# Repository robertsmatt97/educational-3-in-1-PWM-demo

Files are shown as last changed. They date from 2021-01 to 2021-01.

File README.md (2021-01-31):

# educational-3-in-1-PWM-demo
Fall 2019 Power Electronics: Modern Topics Semester Project (with Houshang Salimian Rizi)   
EE 394 Semester Project, assigned by Dr. Alex Hanson   

## Description
The 3-in-1 PWM Converter is used as a visual aid for students to learn about designing basic PWM converters, including the Buck, Boost, and Buck-Boost topologies.   
The converter was designed using KiCAD, with the specifications located in `Project_1.pdf`.   
Instructions on how to use the converter, as well as design choices and improvements, can be found in `User_Manual.pdf`.

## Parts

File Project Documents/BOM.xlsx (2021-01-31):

Q1 | CSD19536KTT | Mosfet_ti | CSD19536KTT
C1 | 4.7u | ul_AMK | AMK107BBJ476MA-RE
C10 | AMK107BBJ476MA-RE | ul_AMK | AMK107BBJ476MA-RE
C11 | 10n | ul_AMK | AMK107BBJ476MA-RE
C12 | 10n | ul_AMK | AMK107BBJ476MA-RE
C13 | 1n | ul_AMK | AMK107BBJ476MA-RE
C14 | AMK107BBJ476MA-RE | ul_AMK | AMK107BBJ476MA-RE
C15 | AMK107BBJ476MA-RE | ul_AMK | AMK107BBJ476MA-RE
C16 | 1u | ul_AMK | AMK107BBJ476MA-RE
C17 | 1u | ul_AMK | AMK107BBJ476MA-RE
C18 | 1u | ul_AMK | AMK107BBJ476MA-RE
C19 | 1u | ul_AMK | AMK107BBJ476MA-RE
C2 | 4.7u | ul_AMK | AMK107BBJ476MA-RE
C20 | 1u | ul_AMK | AMK107BBJ476MA-RE
C21 | 1u | ul_AMK | AMK107BBJ476MA-RE
C3 | 47n-0603-X7S-TDK-100V | ul_AMK | AMK107BBJ476MA-RE
C4 | 47n | ul_C3216C0G2A | C3216C0G2A682J115AA
C5 | 47n | ul_C3216C0G2A | C3216C0G2A682J115AA
C6 | 100p | ul_AMK | AMK107BBJ476MA-RE
C7 | 100n | ul_AMK | AMK107BBJ476MA-RE
C8 | 100n | ul_AMK | AMK107BBJ476MA-RE
C9 | 100n | ul_AMK | AMK107BBJ476MA-RE
J1 | Conn_01x02 | Connector_Generic | Conn_01x02
J2 | Pin_test | Connector | Conn_01x01_Male
J3 | Pin_test | Connector | Conn_01x01_Male
J4 | Pin_test | Connector | Conn_01x01_Male
J5 | Pin_test | Connector | Conn_01x01_Male
J6 | J1_J3 | Micro2 | J1_J3
J7 | J2_J4 | Micro2 | J2_J4
J8 | J5_J7 | Micro2 | J5_J7
J9 | J6_J8 | Micro2 | J6_J8
L1 | 100n | Inductor_680u | SRR1260-100M
L2 | 680u | Inductor_680u | SRR1260-100M
L3 | 680u | Inductor_680u | SRR1260-100M
L4 | 100n | Inductor_680u | SRR1260-100M
R1 | 300R-10W | 300_ohm_power_resistor | SQP10AJB-300R
R10 | 1k | ul_PMR03EZPFU10L0 | PMR03EZPFU10L0
R11 | 1k-1% | ul_PMR03EZPFU10L0 | PMR03EZPFU10L0
R12 | 1k | ul_PMR03EZPFU10L0 | PMR03EZPFU10L0
R13 | 56k-1% | ul_PMR03EZPFU10L0 | PMR03EZPFU10L0
R14 | 56k-1% | ul_PMR03EZPFU10L0 | PMR03EZPFU10L0
R15 | 56k-1% | ul_PMR03EZPFU10L0 | PMR03EZPFU10L0
R16 | 4.7k-1% | ul_PMR03EZPFU10L0 | PMR03EZPFU10L0
R17 | 4.7k-1% | ul_PMR03EZPFU10L0 | PMR03EZPFU10L0
R18 | 4.7k-1% | ul_PMR03EZPFU10L0 | PMR03EZPFU10L0
R19 | Jumper | ul_PMR03EZPFU10L0 | PMR03EZPFU10L0
R2 | 300R-10W | 300_ohm_power_resistor | SQP10AJB-300R
R20 | 4.7k | ul_PMR03EZPFU10L0 | PMR03EZPFU10L0
R21 | 4.7k | ul_PMR03EZPFU10L0 | PMR03EZPFU10L0
R22 | 4.7k | ul_PMR03EZPFU10L0 | PMR03EZPFU10L0
R23 | 4.7k | ul_PMR03EZPFU10L0 | PMR03EZPFU10L0
R3 | Shunt | ul_PMR03EZPFU10L0 | PMR03EZPFU10L0
R4 | 4.7k-1% | ul_PMR03EZPFU10L0 | PMR03EZPFU10L0
R5 | 4.7k-1% | ul_PMR03EZPFU10L0 | PMR03EZPFU10L0
R6 | 4.7k-1% | ul_PMR03EZPFU10L0 | PMR03EZPFU10L0
R7 | 56k-1% | ul_PMR03EZPFU10L0 | PMR03EZPFU10L0
R8 | 56k-1% | ul_PMR03EZPFU10L0 | PMR03EZPFU10L0
R9 | 1k | ul_PMR03EZPFU10L0 | PMR03EZPFU10L0
SW1 | SW_SPST | Switch | SW_SPST
SW2 | SW_Rotary4x3 | Switch | SW_Rotary4x3
SW3 | SW_SPST | Switch | SW_SPST
SW4 | SW_SPST | Switch | SW_SPST
SW5 | SW_SPST | Switch | SW_SPST
SW6 | SW_SPST | Switch | SW_SPST
SW7 | SW_Push | Switch | SW_Push
SW8 | SW_DIP_x03 | Switch | SW_DIP_x03
U1 | CSD19536KTT | Mosfet_ti | CSD19536KTT
U2 | OPA325xxDBV | Amplifier_Operational | OPA330xxDBV
U3 | OPA325xxDBV | Amplifier_Operational | OPA330xxDBV
U4 | OPA325xxDBV | Amplifier_Operational | OPA330xxDBV
U5 | MP1907_Gate_Driver | Houshang | MS1907_Gate_Driver

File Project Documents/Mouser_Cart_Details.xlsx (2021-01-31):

ref | value5 | footprint | part | description | Column1
C1 | UBT2A100MPD8TD | Capacitor_THT:CP_Radial_D8.0mm_P3.50mm | UBT2A100MPD8TD-10uF_Electrolytic_Capacitor | Check, bought 2
C10 | 1n | Kicad Libraries:AMK107BBJ476MA-RE | AMK107BBJ476MA-RE-ul_AMK | Check, bought 18 | 6 1n
C11 | 1u, 15 V | Kicad Libraries:AMK107BBJ476MA-RE | AMK107BBJ476MA-RE-ul_AMK | Check, bought 12 | 4 10n
C12 | 1u, 15V | Kicad Libraries:AMK107BBJ476MA-RE | AMK107BBJ476MA-RE-ul_AMK | Check, bought 10 | 4 50n 100V
C13 | 1n | Kicad Libraries:AMK107BBJ476MA-RE | AMK107BBJ476MA-RE-ul_AMK | Check, bought 4 | 2 100n
C14 | 1u, 15V | Kicad Libraries:AMK107BBJ476MA-RE | AMK107BBJ476MA-RE-ul_AMK | Check, bought 15 | 5 1u, ceramic
C15 | 1n | Kicad Libraries:AMK107BBJ476MA-RE | AMK107BBJ476MA-RE-ul_AMK | Check, bought 5 | 2 1u, elect
C16 | 1n | Kicad Libraries:AMK107BBJ476MA-RE | AMK107BBJ476MA-RE-ul_AMK | Check, bought 6 | 4 10u, 25V
C17 | 1n | Kicad Libraries:AMK107BBJ476MA-RE | AMK107BBJ476MA-RE-ul_AMK | ^
C18 | 4.7u or 10u, 15 V | Kicad Libraries:AMK107BBJ476MA-RE | AMK107BBJ476MA-RE-ul_AMK | ^
C19 | 4.7 or 10u, 15V | Kicad Libraries:AMK107BBJ476MA-RE | AMK107BBJ476MA-RE-ul_AMK | ^
C2 | 50n, 100V, ceramic | Kicad Libraries:AMK107BBJ476MA-RE | AMK107BBJ476MA-RE-ul_AMK | ^
C20 | 10u- 25V | Kicad Libraries:AMK107BBJ476MA-RE | AMK107BBJ476MA-RE-ul_AMK | ^
C21 | 1n | Kicad Libraries:AMK107BBJ476MA-RE | AMK107BBJ476MA-RE-ul_AMK | ^
C22 | 100n | Kicad Libraries:AMK107BBJ476MA-RE | AMK107BBJ476MA-RE-ul_AMK | ^
C23 | 10u- 25V | Kicad Libraries:AMK107BBJ476MA-RE | AMK107BBJ476MA-RE-ul_AMK | ^
C24 | 1u, 16 V | Kicad Libraries:AMK107BBJ476MA-RE | AMK107BBJ476MA-RE-ul_AMK | ^
C25 | 0.1u, 15 V | Kicad Libraries:AMK107BBJ476MA-RE | AMK107BBJ476MA-RE-ul_AMK | ^
C26 | 1u, 15V | Kicad Libraries:AMK107BBJ476MA-RE | AMK107BBJ476MA-RE-ul_AMK | ^
C27 | 4.7u | Kicad Libraries:AMK107BBJ476MA-RE | AMK107BBJ476MA-RE-ul_AMK | ^
C28 | 1u, 60+V, electrolytic | Kicad Libraries:UKL2A0R1KDD | UKL2A0R1KDD-100n_Electrolytic_Capacitor | ^
C29 | 1u, 60+V, electrolytic | Kicad Libraries:UKL2A0R1KDD | UKL2A0R1KDD-100n_Electrolytic_Capacitor | ^
C3 | 50n, 100V, ceramic | Kicad Libraries:AMK107BBJ476MA-RE | AMK107BBJ476MA-RE-ul_AMK | ^
C4 | 50n, 100V, ceramic | Kicad Libraries:AMK107BBJ476MA-RE | AMK107BBJ476MA-RE-ul_AMK | ^
C5 | 50n, 100V, ceramic | Kicad Libraries:AMK107BBJ476MA-RE | AMK107BBJ476MA-RE-ul_AMK | ^
C6 | 10n-0603-X7S-TDK-100V ceramic | Kicad Libraries:AMK107BBJ476MA-RE | AMK107BBJ476MA-RE-ul_AMK | ^
C7 | 10n-0603-X7S-TDK-100V ceramic | Kicad Libraries:AMK107BBJ476MA-RE | AMK107BBJ476MA-RE-ul_AMK | ^
C8 | 10n-0603-X7S-TDK-100V ceramic | Kicad Libraries:AMK107BBJ476MA-RE | AMK107BBJ476MA-RE-ul_AMK | ^
C9 | 10n-0603-X7S-TDK-100V ceramic | Kicad Libraries:AMK107BBJ476MA-RE | AMK107BBJ476MA-RE-ul_AMK | ^
CR1 | MBR1H100SFT3G | Kicad Libraries:MBR1H100SFT3G | MBR1H100SFT3G-Gate_driver_diode | Check, bought 2
D1 | D_Zener | Kicad Libraries:SODFL3516X120N | D_Zener-Device | Check, bought 4
D2 | D_Zener | Kicad Libraries:SODFL3516X120N | D_Zener-Device | ^
J1 | OSTTA020161 | OSTTA020161:SHDR2W130P0X500_1X2_1000X900X1290P | OSTTA020161-OSTTA020161 | Check, bought 2
J1 | OSTTA020161 | OSTTA020161:SHDR2W130P0X500_1X2_1000X900X1290P | OSTTA020161-OSTTA020161 | ^
J1 | OSTTA020161 | OSTTA020161:SHDR2W130P0X500_1X2_1000X900X1290P | OSTTA020161-OSTTA020161 | ^
J1 | OSTTA020161 | OSTTA020161:SHDR2W130P0X500_1X2_1000X900X1290P | OSTTA020161-OSTTA020161 | ^
J2 | J5_J7 | Connector_PinHeader_2.54mm:PinHeader_2x10_P2.54mm_Top_Bottom_Vertical | J5_J7-Micro2 | Check, bought 4
J3 | J6_J8 | Connector_PinHeader_2.54mm:PinHeader_2x10_P2.54mm_Top_Bottom_Vertical | J6_J8-Micro2 | ^
L1 | 1n | MLF2012E120K:INDC2012X105N | SRR1260-100M-Inductor_680u | Check, bought 6
L2 | 1n | MLF2012E120K:INDC2012X105N | SRR1260-100M-Inductor_680u | ^
L3 | 1n | MLF2012E120K:INDC2012X105N | SRR1260-100M-Inductor_680u | ^
L4 | 680u | Kicad Libraries:SRR1260-100M | SRR1260-100M-Inductor_680u | Check, bought 4
L5 | 680u | Kicad Libraries:SRR1260-100M | SRR1260-100M-Inductor_680u | ^
L6 | CVH252009-4R7M | Kicad Libraries:CVH252009-4R7M | CVH252009-4R7M-Boost_Inductor | Check, bought 2
L7 | 100n | MLF2012E120K:INDC2012X105N | SRR1260-100M-Inductor_680u | Check, bought 6
L8 | 100n | MLF2012E120K:INDC2012X105N | SRR1260-100M-Inductor_680u | ^
L9 | 100n | MLF2012E120K:INDC2012X105N | SRR1260-100M-Inductor_680u | ^
PT1 | Probe_test | Extra Libray Parts:Probe_test | Probe_test | -
PT10 | Probe_test | Extra Libray Parts:Probe_test | Probe_test | -
PT11 | Probe_test | Extra Libray Parts:Probe_test | Probe_test | -
PT2 | Probe_test | Extra Libray Parts:Probe_test | Probe_test | -
PT3 | Probe_test | Extra Libray Parts:Probe_test | Probe_test | -
PT4 | Probe_test | Extra Libray Parts:Probe_test | Probe_test | -
PT5 | Probe_test | Extra Libray Parts:Probe_test | Probe_test | -
PT6 | Probe_test | Extra Libray Parts:Probe_test | Probe_test | -
PT7 | Probe_test | Extra Libray Parts:Probe_test | Probe_test | -
PT8 | Probe_test | Extra Libray Parts:Probe_test | Probe_test | -
PT9 | Probe_test | Extra Libray Parts:Probe_test | Probe_test | -
R1 | LTR10EVHFLR240 (250m) | Kicad Libraries:LTR10EVHFLR240 | LTR10EVHFLR240-Shunt_resistor | Check, bought 3
R10 | 1k | Resistor_SMD:R_0603_1608Metric | PMR03EZPFU10L0-ul_PMR03EZPFU10L0 | 3 2R 0603 | check, bought 4
R11 | 47k | Resistor_SMD:R_0603_1608Metric | PMR03EZPFU10L0-ul_PMR03EZPFU10L0 | 3 0R 0603 | check, bought 10
R12 | 47k | Resistor_SMD:R_0603_1608Metric | PMR03EZPFU10L0-ul_PMR03EZPFU10L0 | 5 1k 0603 | check, bought 10
R13 | 47k | Resistor_SMD:R_0603_1608Metric | PMR03EZPFU10L0-ul_PMR03EZPFU10L0 | 5 4.7k-1% 0603 | check, bought 15
R14 | 47k | Resistor_SMD:R_0603_1608Metric | PMR03EZPFU10L0-ul_PMR03EZPFU10L0 | 2 56k-1% 0603 | check, bought 4
R15 | 56k-1% | Resistor_SMD:R_0603_1608Metric | PMR03EZPFU10L0-ul_PMR03EZPFU10L0 | 2 10k 0603 | check, bought 5
R16 | 1k | Resistor_SMD:R_0603_1608Metric | PMR03EZPFU10L0-ul_PMR03EZPFU10L0 | 1 18k 0603 | check, bought 3
R17 | 1k | Resistor_SMD:R_0603_1608Metric | PMR03EZPFU10L0-ul_PMR03EZPFU10L0 | 1 158k 0603 | check, bought 3
R18 | 56k-1% | Resistor_SMD:R_0603_1608Metric | PMR03EZPFU10L0-ul_PMR03EZPFU10L0 | 3 240m 0508 r | check, bought 10
R19 | 10k | Resistor_SMD:R_0603_1608Metric | PMR03EZPFU10L0-ul_PMR03EZPFU10L0 | 2 power | check, bought 5
R2 | 300R-10W | Kicad Libraries:SQP10AJB-300R | SQP10AJB-300R-300_ohm_power_resistor
R20 | 1k | Resistor_SMD:R_0603_1608Metric | PMR03EZPFU10L0-ul_PMR03EZPFU10L0
R21 | 10k | Resistor_SMD:R_0603_1608Metric | PMR03EZPFU10L0-ul_PMR03EZPFU10L0
R22 | 1k | Resistor_SMD:R_0603_1608Metric | PMR03EZPFU10L0-ul_PMR03EZPFU10L0
R23 | 4.7k-1% | Resistor_SMD:R_0603_1608Metric | PMR03EZPFU10L0-ul_PMR03EZPFU10L0
R24 | 2R | Resistor_SMD:R_0603_1608Metric | PMR03EZPFU10L0-ul_PMR03EZPFU10L0
R25 | 24k | Resistor_SMD:R_0603_1608Metric | PMR03EZPFU10L0-ul_PMR03EZPFU10L0
R26 | 18k | Resistor_SMD:R_0603_1608Metric | PMR03EZPFU10L0-ul_PMR03EZPFU10L0
R27 | 158k | Resistor_SMD:R_0603_1608Metric | PMR03EZPFU10L0-ul_PMR03EZPFU10L0
R28 | 2R | Resistor_SMD:R_0603_1608Metric | PMR03EZPFU10L0-ul_PMR03EZPFU10L0
R29 | 2R | Resistor_SMD:R_0603_1608Metric | PMR03EZPFU10L0-ul_PMR03EZPFU10L0
R3 | 300R-10W | Kicad Libraries:SQP10AJB-300R | SQP10AJB-300R-300_ohm_power_resistor
R30 | 240m | Kicad Libraries:LTR10EVHFLR240 | LTR10EVHFLR240-Shunt_resistor
R4 | 240m | Kicad Libraries:LTR10EVHFLR240 | LTR10EVHFLR240-Shunt_resistor
R5 | 240m | Kicad Libraries:LTR10EVHFLR240 | LTR10EVHFLR240-Shunt_resistor
R6 | 4.7k-1% | Resistor_SMD:R_0603_1608Metric | PMR03EZPFU10L0-ul_PMR03EZPFU10L0
R7 | 4.7k-1% | Resistor_SMD:R_0603_1608Metric | PMR03EZPFU10L0-ul_PMR03EZPFU10L0
R8 | 4.7k-1% | Resistor_SMD:R_0603_1608Metric | PMR03EZPFU10L0-ul_PMR03EZPFU10L0
R9 | 4.7k-1% | Resistor_SMD:R_0603_1608Metric | PMR03EZPFU10L0-ul_PMR03EZPFU10L0
SW1 | R1966ABLKBLKEF | Extra Libray Parts:R1966ABLKBLKEF | R1966ABLKBLKEF-R1966ABLKBLKEF | 4P3T | Check, bought 3
SW1 | R1966ABLKBLKEF | Extra Libray Parts:R1966ABLKBLKEF | R1966ABLKBLKEF-R1966ABLKBLKEF | 5 Rocker | Check, bought 7
SW1 | R1966ABLKBLKEF | Extra Libray Parts:R1966ABLKBLKEF | R1966ABLKBLKEF-R1966ABLKBLKEF | 1 DIP | Check, bought 3
SW1 | R1966ABLKBLKEF | Extra Libray Parts:R1966ABLKBLKEF | R1966ABLKBLKEF-R1966ABLKBLKEF
SW1 | R1966ABLKBLKEF | Extra Libray Parts:R1966ABLKBLKEF | R1966ABLKBLKEF-R1966ABLKBLKEF
SW1 | R1966ABLKBLKEF | Extra Libray Parts:R1966ABLKBLKEF | R1966ABLKBLKEF-R1966ABLKBLKEF
SW2 | EG4319 | Extra Libray Parts:EG4319 | EG4319-EG4319
SW2 | EG4319 | Extra Libray Parts:EG4319 | EG4319-EG4319
SW2 | EG4319 | Extra Libray Parts:EG4319 | EG4319-EG4319
SW2 | EG4319 | Extra Libray Parts:EG4319 | EG4319-EG4319
SW2 | EG4319 | Extra Libray Parts:EG4319 | EG4319-EG4319
SW2 | EG4319 | Extra Libray Parts:EG4319 | EG4319-EG4319
SW3 | R1966ABLKBLKEF | Extra Libray Parts:R1966ABLKBLKEF | R1966ABLKBLKEF-R1966ABLKBLKEF
SW3 | R1966ABLKBLKEF | Extra Libray Parts:R1966ABLKBLKEF | R1966ABLKBLKEF-R1966ABLKBLKEF
SW3 | R1966ABLKBLKEF | Extra Libray Parts:R1966ABLKBLKEF | R1966ABLKBLKEF-R1966ABLKBLKEF
SW3 | R1966ABLKBLKEF | Extra Libray Parts:R1966ABLKBLKEF | R1966ABLKBLKEF-R1966ABLKBLKEF
SW3 | R1966ABLKBLKEF | Extra Libray Parts:R1966ABLKBLKEF | R1966ABLKBLKEF-R1966ABLKBLKEF
SW3 | R1966ABLKBLKEF | Extra Libray Parts:R1966ABLKBLKEF | R1966ABLKBLKEF-R1966ABLKBLKEF
SW4 | R1966ABLKBLKEF | Extra Libray Parts:R1966ABLKBLKEF | R1966ABLKBLKEF-R1966ABLKBLKEF
SW4 | R1966ABLKBLKEF | Extra Libray Parts:R1966ABLKBLKEF | R1966ABLKBLKEF-R1966ABLKBLKEF
SW4 | R1966ABLKBLKEF | Extra Libray Parts:R1966ABLKBLKEF | R1966ABLKBLKEF-R1966ABLKBLKEF
SW4 | R1966ABLKBLKEF | Extra Libray Parts:R1966ABLKBLKEF | R1966ABLKBLKEF-R1966ABLKBLKEF
SW4 | R1966ABLKBLKEF | Extra Libray Parts:R1966ABLKBLKEF | R1966ABLKBLKEF-R1966ABLKBLKEF
SW4 | R1966ABLKBLKEF | Extra Libray Parts:R1966ABLKBLKEF | R1966ABLKBLKEF-R1966ABLKBLKEF
SW5 | R1966ABLKBLKEF | Extra Libray Parts:R1966ABLKBLKEF | R1966ABLKBLKEF-R1966ABLKBLKEF
SW5 | R1966ABLKBLKEF | Extra Libray Parts:R1966ABLKBLKEF | R1966ABLKBLKEF-R1966ABLKBLKEF
SW5 | R1966ABLKBLKEF | Extra Libray Parts:R1966ABLKBLKEF | R1966ABLKBLKEF-R1966ABLKBLKEF
SW5 | R1966ABLKBLKEF | Extra Libray Parts:R1966ABLKBLKEF | R1966ABLKBLKEF-R1966ABLKBLKEF
SW5 | R1966ABLKBLKEF | Extra Libray Parts:R1966ABLKBLKEF | R1966ABLKBLKEF-R1966ABLKBLKEF
SW5 | R1966ABLKBLKEF | Extra Libray Parts:R1966ABLKBLKEF | R1966ABLKBLKEF-R1966ABLKBLKEF
SW6 | ADE04S04 | extra parts:ADE04S04 | ADE04S04-ADE04S04
SW6 | ADE04S04 | extra parts:ADE04S04 | ADE04S04-ADE04S04
SW6 | ADE04S04 | extra parts:ADE04S04 | ADE04S04-ADE04S04
SW6 | ADE04S04 | extra parts:ADE04S04 | ADE04S04-ADE04S04
SW6 | ADE04S04 | extra parts:ADE04S04 | ADE04S04-ADE04S04
SW6 | ADE04S04 | extra parts:ADE04S04 | ADE04S04-ADE04S04
SW7 | R1966ABLKBLKEF | Extra Libray Parts:R1966ABLKBLKEF | R1966ABLKBLKEF-R1966ABLKBLKEF
SW7 | R1966ABLKBLKEF | Extra Libray Parts:R1966ABLKBLKEF | R1966ABLKBLKEF-R1966ABLKBLKEF
SW7 | R1966ABLKBLKEF | Extra Libray Parts:R1966ABLKBLKEF | R1966ABLKBLKEF-R1966ABLKBLKEF
SW7 | R1966ABLKBLKEF | Extra Libray Parts:R1966ABLKBLKEF | R1966ABLKBLKEF-R1966ABLKBLKEF
SW7 | R1966ABLKBLKEF | Extra Libray Parts:R1966ABLKBLKEF | R1966ABLKBLKEF-R1966ABLKBLKEF
SW7 | R1966ABLKBLKEF | Extra Libray Parts:R1966ABLKBLKEF | R1966ABLKBLKEF-R1966ABLKBLKEF
U1 | CSD19538Q3AT | Kicad Libraries:CSD19538Q3AT | CSD19538Q3AT-MOSFET | Check, bought 10
U2 | CSD19538Q3AT | Kicad Libraries:CSD19538Q3AT | CSD19538Q3AT-MOSFET | ^
U3 | OPA325xxDBV | Kicad Libraries:OPA320SAIDBVT | OPA330xxDBV-Amplifier_Operational | Check, bought 3
U4 | LMP8640HVMK-H_NOPB | Extra Libray Parts:SOT95P280X110-6N | LMP8640HVMK-H_NOPB-LMP8640HVMK-H_NOPB | check, bought 2
U4 | LMP8640HVMK-H_NOPB | Extra Libray Parts:SOT95P280X110-6N | LMP8640HVMK-H_NOPB-LMP8640HVMK-H_NOPB | ^
U4 | LMP8640HVMK-H_NOPB | Extra Libray Parts:SOT95P280X110-6N | LMP8640HVMK-H_NOPB-LMP8640HVMK-H_NOPB | ^
U4 | LMP8640HVMK-H_NOPB | Extra Libray Parts:SOT95P280X110-6N | LMP8640HVMK-H_NOPB-LMP8640HVMK-H_NOPB | ^
U4 | LMP8640HVMK-H_NOPB | Extra Libray Parts:SOT95P280X110-6N | LMP8640HVMK-H_NOPB-LMP8640HVMK-H_NOPB | ^
U4 | LMP8640HVMK-H_NOPB | Extra Libray Parts:SOT95P280X110-6N | LMP8640HVMK-H_NOPB-LMP8640HVMK-H_NOPB | ^
U5 | TPS61085TDGKR | Kicad Libraries:TPS61085TDGKR | LMP8640HVMK-H_NOPB-LMP8640HVMK-H_NOPB | Check, bought 3
U6 | LM5109BMA | Kicad Libraries:LM5109BMA | LMP8640HVMK-H_NOPB-LMP8640HVMK-H_NOPB | Check, bought 3
U7 | PMEG2010AEH | Kicad Libraries:SODFL3516X120N | LMP8640HVMK-H_NOPB-LMP8640HVMK-H_NOPB | Check, bought 3
U7 | PMEG2010AEH | Kicad Libraries:SODFL3516X120N | LMP8640HVMK-H_NOPB-LMP8640HVMK-H_NOPB
U7 | PMEG2010AEH | Kicad Libraries:SODFL3516X120N | LMP8640HVMK-H_NOPB-LMP8640HVMK-H_NOPB
U7 | PMEG2010AEH | Kicad Libraries:SODFL3516X120N | LMP8640HVMK-H_NOPB-LMP8640HVMK-H_NOPB
U7 | PMEG2010AEH | Kicad Libraries:SODFL3516X120N | LMP8640HVMK-H_NOPB-LMP8640HVMK-H_NOPB
VR1 | PTV09A-4020U-B103 | Extra Libray Parts:PTV09A4015FB103 | LMP8640HVMK-H_NOPB-LMP8640HVMK-H_NOPB | 2 knobs | Check, bought
VR1 | PTV09A-4020U-B103 | Extra Libray Parts:PTV09A4015FB103 | LMP8640HVMK-H_NOPB-LMP8640HVMK-H_NOPB
VR1 | PTV09A-4020U-B103 | Extra Libray Parts:PTV09A4015FB103 | LMP8640HVMK-H_NOPB-LMP8640HVMK-H_NOPB
VR1 | PTV09A-4020U-B103 | Extra Libray Parts:PTV09A4015FB103 | LMP8640HVMK-H_NOPB-LMP8640HVMK-H_NOPB
VR1 | PTV09A-4020U-B103 | Extra Libray Parts:PTV09A4015FB103 | LMP8640HVMK-H_NOPB-LMP8640HVMK-H_NOPB
VR1 | PTV09A-4020U-B103 | Extra Libray Parts:PTV09A4015FB103 | LMP8640HVMK-H_NOPB-LMP8640HVMK-H_NOPB
VR2 | PTV09A-4020U-B103 | Extra Libray Parts:PTV09A4015FB103 | LMP8640HVMK-H_NOPB-LMP8640HVMK-H_NOPB
VR2 | PTV09A-4020U-B103 | Extra Libray Parts:PTV09A4015FB103 | LMP8640HVMK-H_NOPB-LMP8640HVMK-H_NOPB
VR2 | PTV09A-4020U-B103 | Extra Libray Parts:PTV09A4015FB103 | LMP8640HVMK-H_NOPB-LMP8640HVMK-H_NOPB
VR2 | PTV09A-4020U-B103 | Extra Libray Parts:PTV09A4015FB103 | LMP8640HVMK-H_NOPB-LMP8640HVMK-H_NOPB
VR2 | PTV09A-4020U-B103 | Extra Libray Parts:PTV09A4015FB103 | LMP8640HVMK-H_NOPB-LMP8640HVMK-H_NOPB
VR2 | PTV09A-4020U-B103 | Extra Libray Parts:PTV09A4015FB103 | LMP8640HVMK-H_NOPB-LMP8640HVMK-H_NOPB

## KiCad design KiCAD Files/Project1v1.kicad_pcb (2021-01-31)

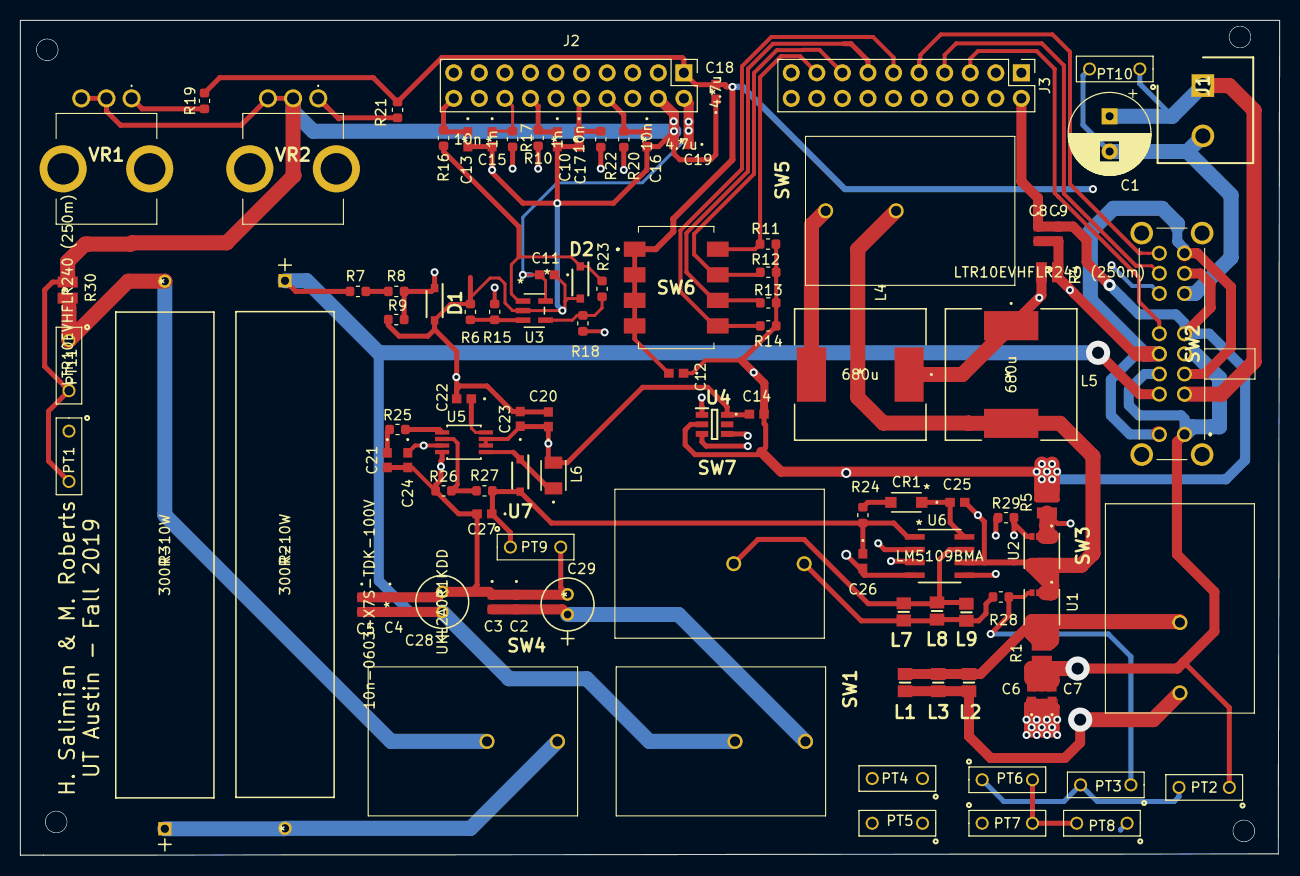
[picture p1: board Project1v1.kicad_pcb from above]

Board: 4 copper layers, 125.1 x 82.9 mm, 101 parts (0 on the bottom side), 52 nets.

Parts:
C1: UBT2A100MPD8TD; CP_Radial_D8.0mm_P3.50mm
C2, C3, C4, C5, C6, C7, C8, C9: 10n-0603-X7S-TDK-100V; AMK107BBJ476MA-RE
C10, C15: 1n; AMK107BBJ476MA-RE
C11, C22: 100n; AMK107BBJ476MA-RE
C12, C14, C24: 1u; AMK107BBJ476MA-RE
C13, C16, C17: 10n; AMK107BBJ476MA-RE
C18, C19, C20, C27: 4.7u; AMK107BBJ476MA-RE
C21: 1.6n; AMK107BBJ476MA-RE
C23: 1u - 25 V; AMK107BBJ476MA-RE
C25: 0.1u; AMK107BBJ476MA-RE
C26: AMK107BBJ476MA-RE
C28, C29: UKL2A0R1KDD
CR1: MBR1H100SFT3G
D1, D2: D_Zener; SODFL3516X120N
J1: OSTTA020161; SHDR2W130P0X500_1X2_1000X900X1290P
J2: J5_J7; PinHeader_2x10_P2.54mm_Top_Bottom_Vertical
J3: J6_J8; PinHeader_2x10_P2.54mm_Top_Bottom_Vertical
L1, L2, L3: 1n; INDC2012X105N
L4, L5: 680u; SRR1260-100M
L6: CVH252009-4R7M
L7, L8, L9: 100n; INDC2012X105N
PT1, PT2, PT3, PT4, PT5, PT6, PT7, PT8, PT9, PT10, PT11: Probe_test
R1, R4, R5, R30: LTR10EVHFLR240 (250m); LTR10EVHFLR240
R2, R3: 300R-10W; SQP10AJB-300R
R6, R7, R8, R9, R23: 4.7k-1%; R_0603_1608Metric
R10, R16, R17: 10k; R_0603_1608Metric
R11, R12, R13, R14, R19, R20, R21, R22: 47k; R_0603_1608Metric
R15, R18: 56k-1%; R_0603_1608Metric
R24, R28, R29: 2R; R_0603_1608Metric
R25: 27k; R_0603_1608Metric
R26: 18k; R_0603_1608Metric
R27: 158k; R_0603_1608Metric
SW1, SW3, SW4, SW5, SW7: R1966ABLKBLKEF
SW2: EG4319
SW6: ADE04S04
U1, U2: CSD19538Q3AT
U3: OPA325xxDBV; OPA320SAIDBVT
U4: LMP8640HVMK-H_NOPB; SOT95P280X110-6N
U5: TPS61085TDGKR
U6: LM5109BMA
U7: PMEG2010AEH; SODFL3516X120N
VR1, VR2: PTV09A-4020U-B103; PTV09A4015FB103

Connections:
+3V3: C12.2, C18.2, J2.1, R19.2, R21.2, SW2.14, SW6.1, SW6.3, SW6.5, SW6.7
+5V: C11.2, C14.1, C19.1, C20.1, C23.1, C24.1, J2.11, L6.2, U3.5, U4.6, U5.3, U5.6, U5.7
+12V: C26.1, C27.1, PT9.1, R24.1, R27.2, U6.1, U7.2
B+: C1.1, J1.1, PT10.1, R15.2, SW2.2
B-: C1.2, J1.2, PT10.2, R18.2, SW2.6
Boost: J3.4, SW2.15
Buck: J3.3, SW2.13
Buck_Boost: J3.5, SW2.16
C1: C6.2, C7.2, PT2.1, R1.1, SW2.1, SW2.4, SW2.11
C2: C8.2, C9.2, PT4.2, PT5.2, R4.1, SW2.3, SW2.8, SW2.9, SW2.12, U4.4
C3: C2.1, C3.1, C4.1, C5.1, C6.1, C7.1, C8.1, C9.1, C10.2, C11.1, C12.1, C13.2, C14.2, C15.2, C16.2, C17.2, C18.1, C19.2, C20.2, C21.2, C22.2, C23.2, C24.2, C26.2, C27.2, C28.2, C29.2, D1.2, D2.2, J2.12, J3.11, PT1.2, PT6.2, PT7.2, PT8.2, PT9.2, PT11.2, R5.2, R6.1, R9.2, R11.1, R12.1, R13.1, R14.1, R26.1, R30.2, SW2.5, SW2.7, U3.2, U4.2, U5.4, U6.4, VR1.2, VR1.3, VR2.2, VR2.3
CCM-DCM: J3.6, R14.2, SW6.8
Duty_Cycle_Knob: C17.1, J2.15, R22.1
Freq-Sweep: J3.7, R13.2, SW6.6
Freq_Knob: C16.1, J2.14, R20.1
I_ind_p: L4.1, L5.1, PT5.1, R4.2, U4.3
I_switch: PT8.1, R5.1, U2.1, U2.2, U2.3
I_switch_meas: C15.1, J2.18, R17.1
unnamed: C2.2, C3.2, C29.1, SW1.2
unnamed: C21.1, R25.1
unnamed: C22.1, U5.8
unnamed: C25.1, CR1.1, U6.8
unnamed: CR1.2, R24.2
unnamed: D1.1, R8.1, R9.1, R10.2
unnamed: D2.1, R16.2, R23.1, U3.1
unnamed: L1.1, L2.1, L3.1, R1.2, SW3.1, U1.5, U1.6, U1.7, U1.8
unnamed: L4.2, SW5.2
unnamed: L6.1, U5.5, U7.1
unnamed: L7.1, L8.1, L9.1, R28.1, SW7.2
unnamed: PT11.1, R3.2, R30.1, SW4.1
unnamed: R2.2, R3.1, SW4.2
unnamed: R7.1, R8.2
unnamed: R6.2, R15.1, U3.3
unnamed: R17.2, U4.1
unnamed: R18.1, R23.2, U3.4
unnamed: R19.1, R20.2, VR1.1
unnamed: R21.1, R22.2, VR2.1
unnamed: R25.2, U5.1
unnamed: R26.2, R27.1, U5.2
OL-CL: J3.8, R12.2, SW6.4
Preset: J3.9, R11.2, SW6.2
R+: C4.2, C5.2, C28.1, PT1.1, R2.1, R7.2, SW1.1, SW2.10
S1: PT3.1, R28.2, U1.4
S2: PT7.1, R29.2, U2.4
Signal1: J3.1, U6.2
Signal2: J3.2, U6.3
Switch_Node: C25.2, L5.2, PT2.2, PT3.2, PT4.1, PT6.1, SW5.1, U1.1, U1.2, U1.3, U2.5, U2.6, U2.7, U2.8, U6.6
Vin_meas: C13.1, J2.20, R16.1
Vout_meas: C10.1, J2.17, R10.1
gate1: L7.2, L8.2, L9.2, SW7.1, U6.7
gate2: R29.1, U6.5
wire1-: L1.2, L2.2, L3.2, SW3.2

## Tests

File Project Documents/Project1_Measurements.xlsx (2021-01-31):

Step 1:
 |  | Input/Output Voltage |  | Misc Measurements
 | Buck | TEK00003.PNG |  | Input Voltage : 15V
 | Boost | TEK00005.PNG |  | Duty Cycle: 50%
 | BB | TEK00004.PNG |  | Switching Freq: 100 kHz
 |  |  |  | ASyncronous
Step 2:
 |  | Inductor Ripple | Capacitor Ripple
 | Buck | TEK00011.PNG | TEK00008.PNG | Max Ripple
 | Boost | TEK00006.PNG | TEK00007.PNG | Same as above
 | BB | TEK00010PNG | TEK00009.PNG | Buck Iripp now fsw 200khz
Step 3:
 |  | Gate/Switch Node Voltage
 | Buck | TEK00012.PNG
 | Boost | TEK00014.PNG
 | BB | TEK00013.PNG
Step 4:
 |  | Buck Inductor (Open) | Buck Inductor (Closed) | Buck Capacitor (Open) | Buck Capacitor (Closed)
 | Buck | TEK00023.PNG | TEK00024.PNG | TEK00022.PNG | TEK00021.PNG |  | Switch 1
 | Boost | TEK00018.PNG | TEK00017.PNG | TEK00020.PNG | TEK00019.PNG |  | Switch 5
Step 5:
 |  | Drain+Diode Current Ton (High) | Drain+Diode Current Toff (High) | Drain+Diode Current Both (High) | Drain+Diode Current Ton (Low) | Drain+Diode Current Toff (Low) | Drain+Diode Current Both (High)
Boost | Asyncronous | TEK00047.PNG | TEK00048.PNG | TEK00049.PNG | TEK00050.PNG | TEK00051.PNG | TEK00052.PNG
Fsw = 200 kHz | Syncronous (80ns) | TEK00058.PNG | TEK00061.PNG | TEK00062.PNG | TEK00053.PNG | TEK00056.PNG | TEK00057.PNG
 | Syncronous (170ns) | TEK00067.PNG | TEK00065.PNG | TEK00069.PNG | TEK00063.PNG | TEK00064.PNG | TEK00065.PNG
Step 6 (Elective):
 |  | Gate+Drain(Perfect) | Gate+Drain(drain-changed) | Gate+Drain(gate-changed)
Fsw = 200 kHz | Without R | TEK00033.PNG | NA | TEK00034.PNG
Buck | With R | TEK00093.PNG | TEK00028.PNG | TEK00094.PNG
Step 7: | Same as Step 5
Step 8: | Same as Step 5
Step 9:
 |  | Inductor+Capacitor
Buck | fsw = 50 kHz | TEK00073.PNG |  | AC Coupled
Asynchronous | fsw = 200 kHz | TEK00070.PNG |  | Reduced Load
Vin = 20V | fsw = 400 kHz | TEK00072.PNG
Step 10:
 |  | Inductor+Output/High Sw Voltage | Current
Vin = 15V | CCM (Fsw = 400 kHz) | TEK00083.PNG | TEK00082.PNG
Asynchronous | DCM (Fsw = 40 kHz) | TEK00074.PNG
Buck | BCM (Fsw = 167 kHz) | TEK00081.PNG | TEK00078.PNG
 | VS (Fsw = 68.46 kHz) | TEK00075.PNG | TEK00076.PNG
Step 11:
 |  | Input, Output |  | Boost lim = 30V
Synchronous | Boost | TEK00089.PNG | Also include Duty Cycle on CCS | Vin = 5V | Vin = 10V | Vin = 15
Fsw = 200 kHz | BB | TEK00090.PNG + 91 |  | BB lim = 25V
Step 12: |  | Output+Inductor (Synchronous) | Output+Inductor (Asynchronous)
Vin = 20 V | Open Loop | TEK00087.PNG | TEK00086.PNG
Fsw = 200 kHz | Closed Loop | TEK00084.PNG | TEK00085.PNG
Triangular CM
 |  | Gate+Drain (Low Side) Zoomed in | Gate+Drain (Low Side) | Inductor Current
Synchronous |  | TEK00095.PNG | TEK00096.PNG | TEK00097.PNG
Buck
Vin = 10V

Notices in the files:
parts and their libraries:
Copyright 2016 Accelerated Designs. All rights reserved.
